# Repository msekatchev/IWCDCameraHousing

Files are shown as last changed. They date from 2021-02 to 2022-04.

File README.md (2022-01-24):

# IWCDCameraHousing

* metalHousingDesign contains SolidWorks files for the metal housing, and engineering drawings for the parts that need to be machined. 
  * Material purchase list can be found [here](https://docs.google.com/spreadsheets/d/14c0sQv2Obbbmb6hUaK7rj2h6zKZg8cWHZIx4L92i6jI/edit?usp=sharing)
  * Slides describing housing design components and how they fit together can be found [here](https://docs.google.com/presentation/d/12adMD3R-Cg0-MqwHe-JcQx2A3TCLKN2Yq-lHiGlGRaA/edit?usp=sharing)

Both the EzTops and Nautilus models are currently with the original cylinder length.
They use XDE2534.SLDPRT (original length pipe) instead of XDE2534-cut.SLDPRT (my cut pipe) because changing the pipe length breaks all of the mates between the parts. I haven't found a simple fix for this yet.

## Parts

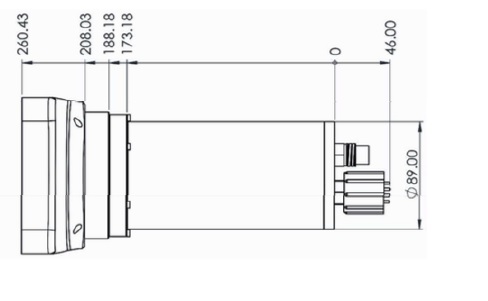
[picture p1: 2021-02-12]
solidworks parts and assembly/camera.jpg

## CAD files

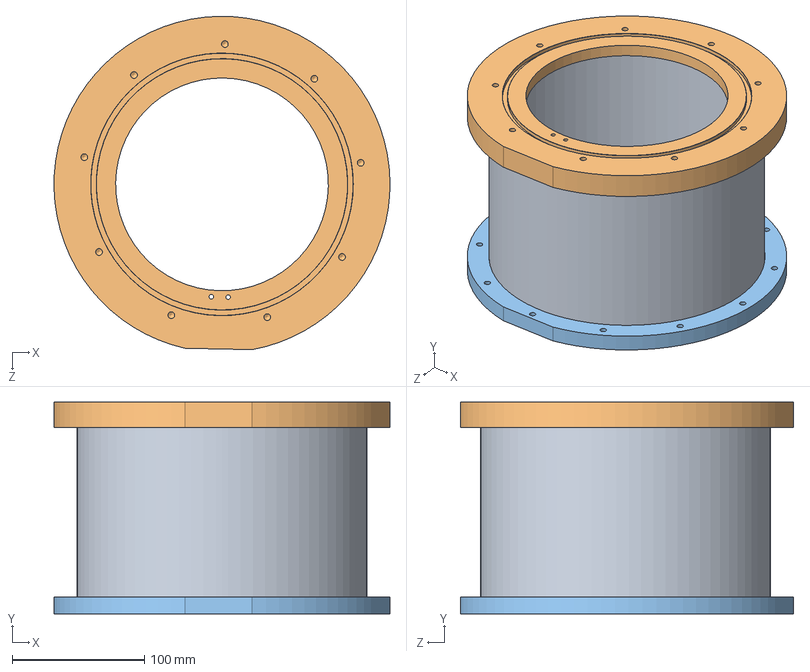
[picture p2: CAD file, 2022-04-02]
metalHousingDesign/Rayotek-Welded-Assembly.SLDASM
253.9 x 160.0 x 251.9 mm
XDE2534
XDE2535
XDE2536

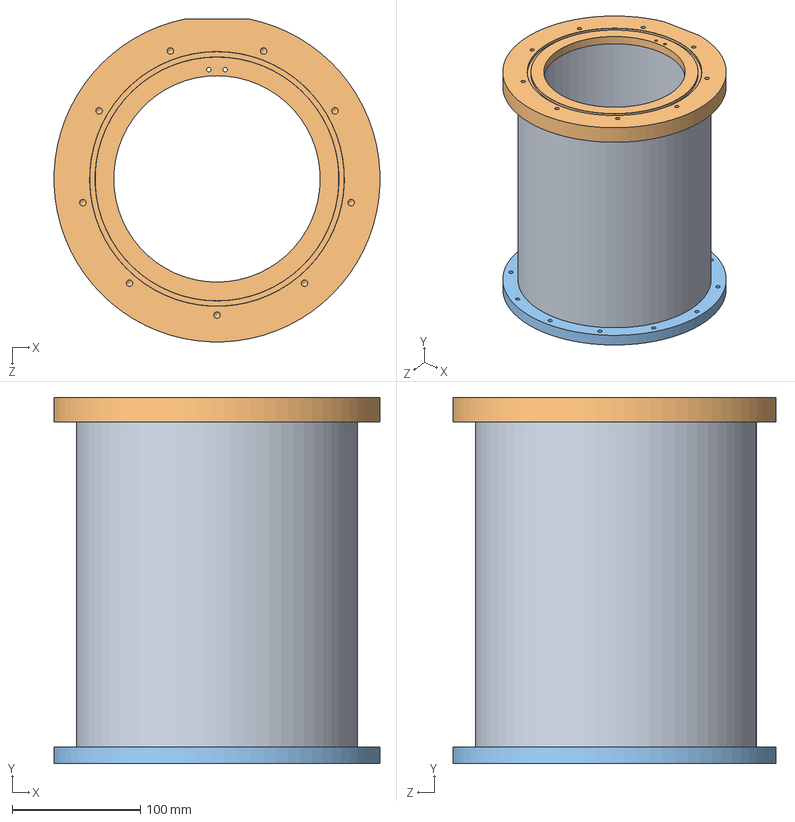
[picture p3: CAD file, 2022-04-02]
metalHousingDesign/XDE2533.SLDASM
253.8 x 285.1 x 251.3 mm
XDE2534
XDE2535
XDE2536

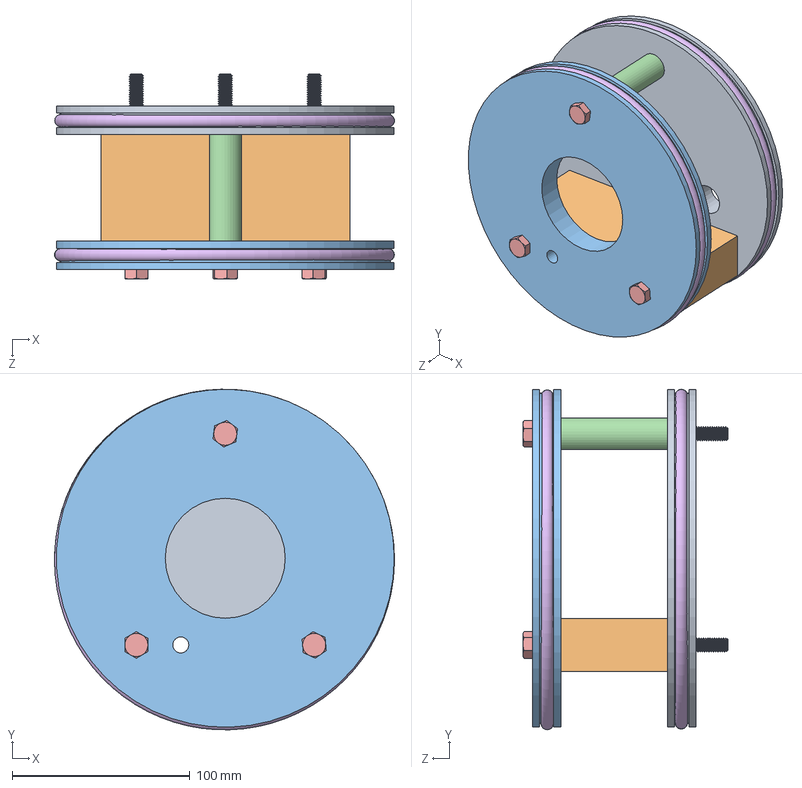
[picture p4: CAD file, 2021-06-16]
solidworks parts and assembly/piston-Assembly.SLDASM
191.2 x 191.5 x 115.3 mm
piston-BackRing
piston-CameraPlate
piston-FrontRing
piston-SpacerTube
BOLT M8x110mm x 3
piston-7inO-RING x 2

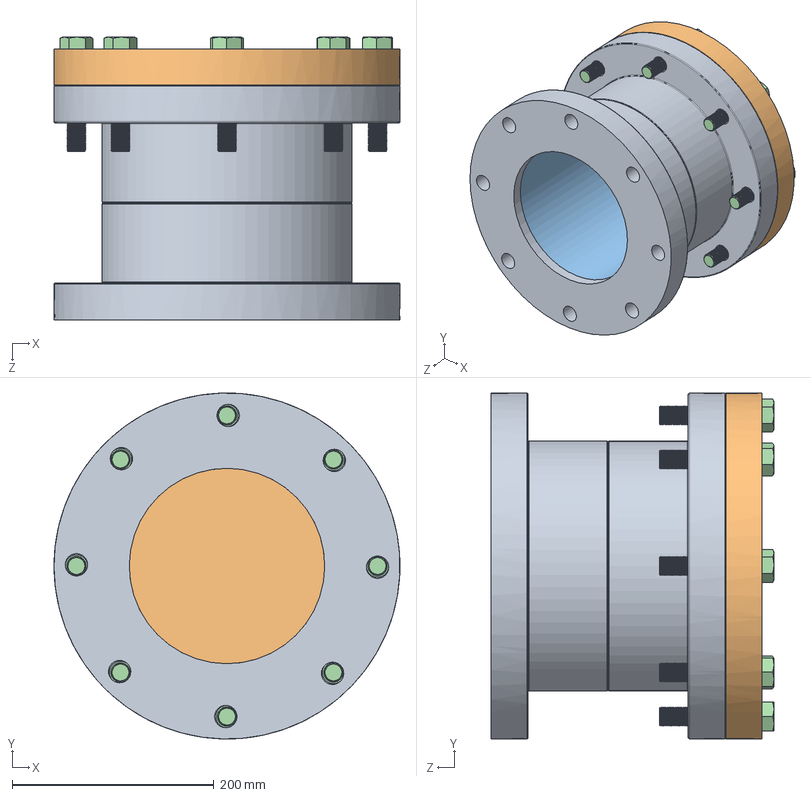
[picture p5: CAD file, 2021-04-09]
solidworks parts and assembly/externalHousing-Assembly.SLDASM
342.9 x 342.8 x 280.2 mm
8in PVC Flange x 2
8in PVC Flange Closed
8in PVC Pipe
BOLT 3-4in x 4in x 8

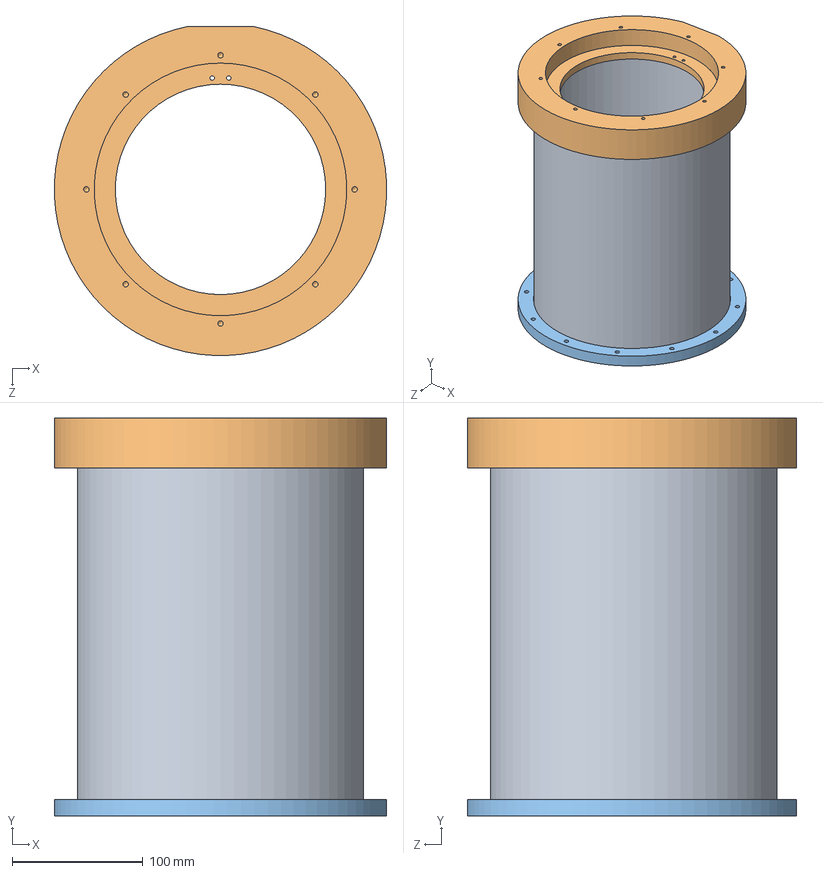
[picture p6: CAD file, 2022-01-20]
metalHousingDesign/XDE2554.SLDASM
253.8 x 304.1 x 251.3 mm
XDE2534
XDE2540
XDE2536

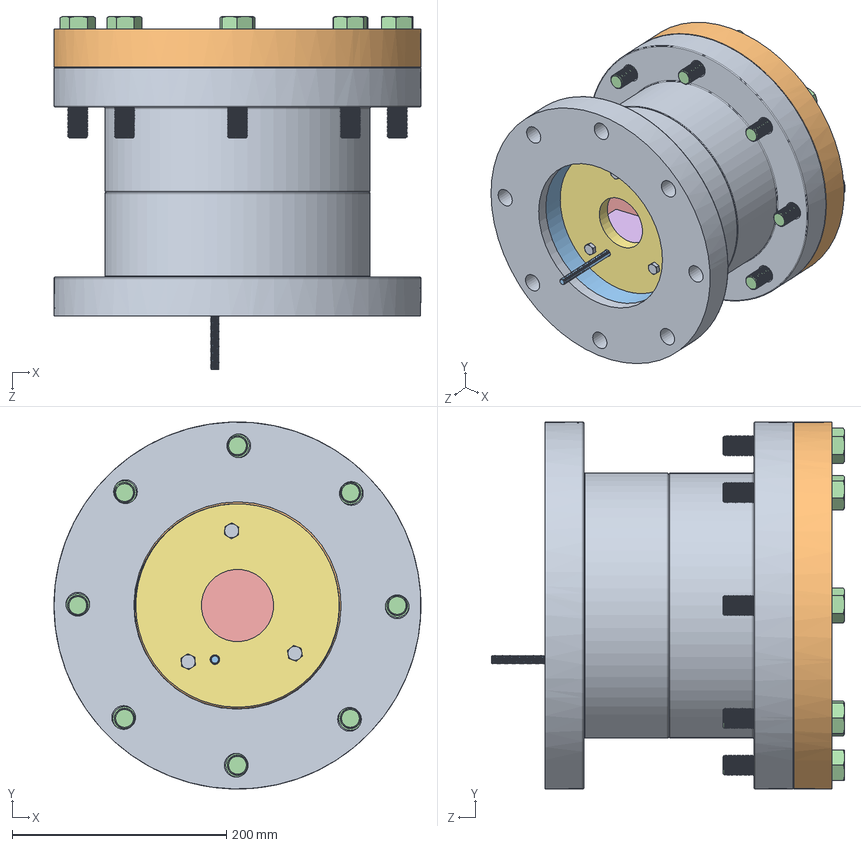
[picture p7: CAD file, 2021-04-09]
solidworks parts and assembly/Photogrametry_V5-PVC.SLDASM
342.9 x 342.8 x 330.2 mm
8in PVC Flange x 2
8in PVC Flange Closed
8in PVC Pipe
BOLT 3-4in x 4in x 8
piston-BackRing
piston-CameraPlate
piston-FrontRing
piston-SpacerTube
BOLT M8x110mm x 3
piston-7inO-RING x 2
ROD M8 150mm
SPRING

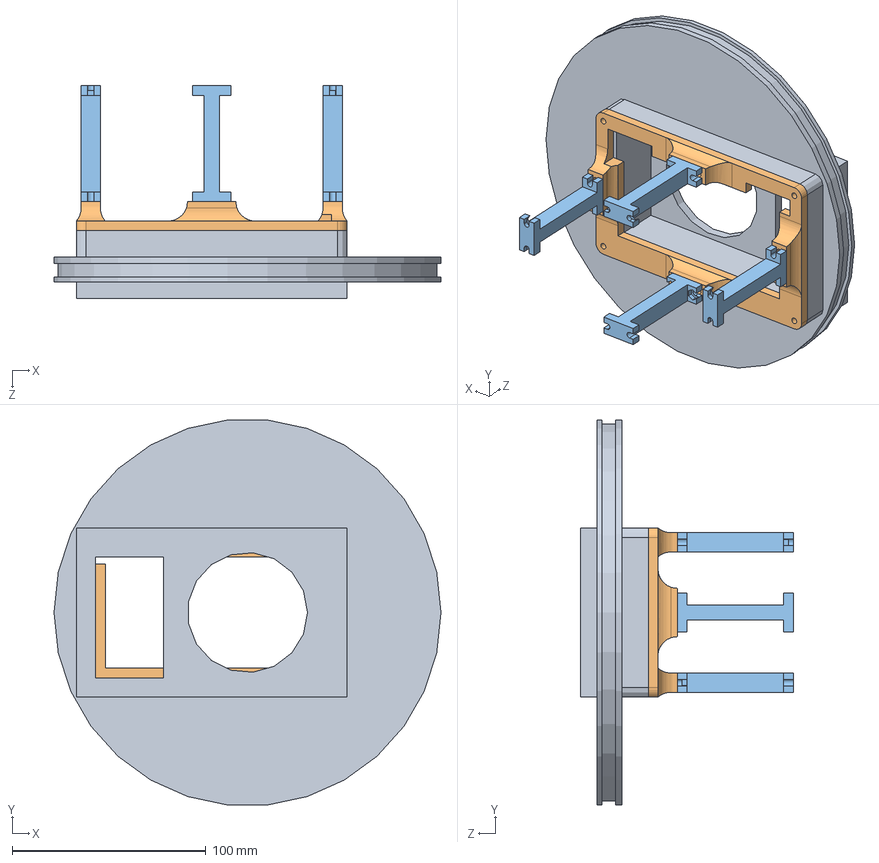
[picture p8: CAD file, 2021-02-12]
solidworks parts and assembly/Camera Mounting_V2.SLDASM
200.0 x 198.9 x 110.0 mm
Camera Case V2
Camera Case-2_V2
Pillars x 4

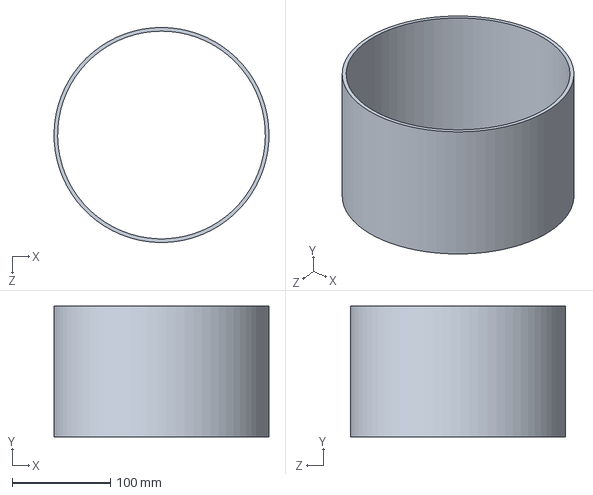
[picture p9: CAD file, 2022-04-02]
metalHousingDesign/XDE2534.SLDPRT
219.0 x 133.4 x 219.1 mm

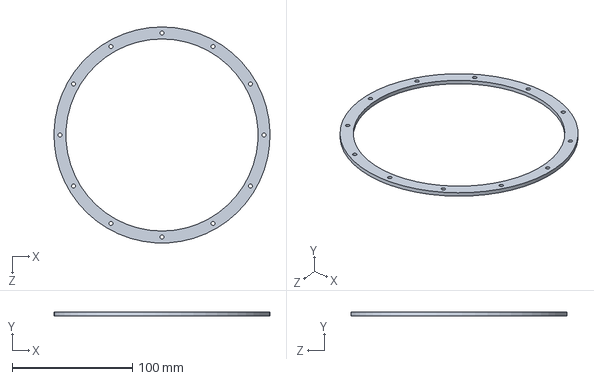
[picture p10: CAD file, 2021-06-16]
solidworks parts and assembly/PVC Parts/clamp-ring.SLDPRT
179.9 x 3.00 x 180.0 mm

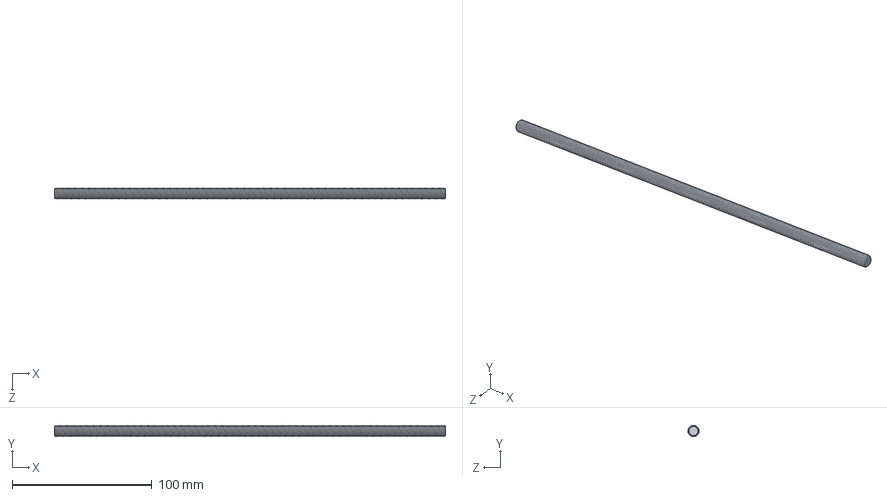
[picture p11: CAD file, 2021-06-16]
solidworks parts and assembly/ROD M8 150mm.SLDPRT
280.0 x 8.00 x 8.00 mm

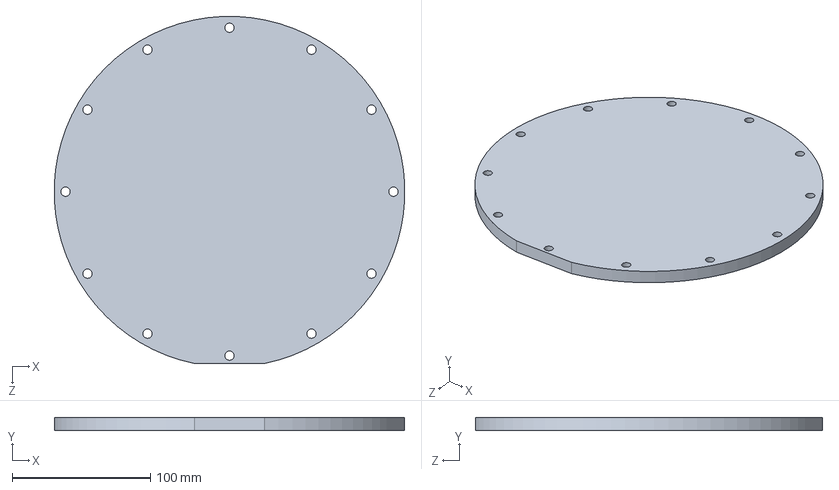
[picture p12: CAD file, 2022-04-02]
metalHousingDesign/XDE2537-blank.SLDPRT
253.8 x 9.53 x 251.3 mm

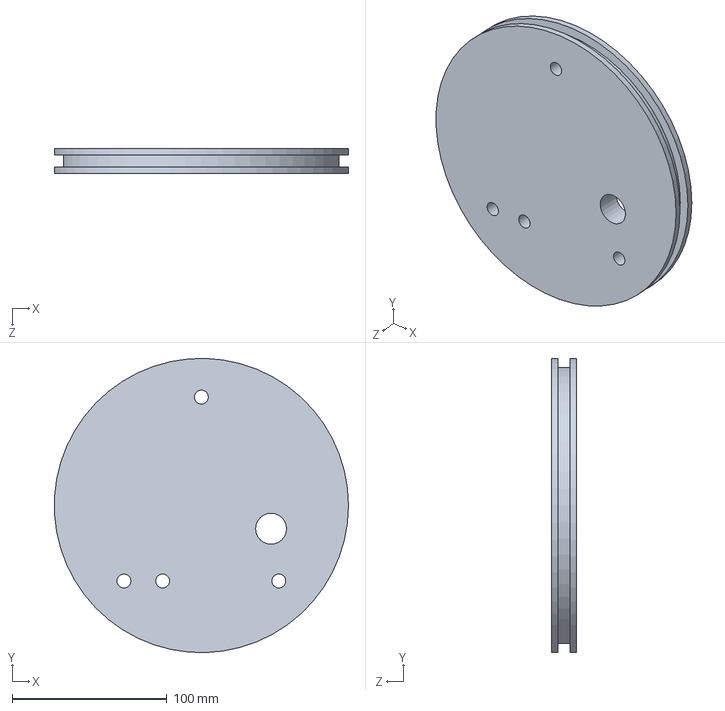
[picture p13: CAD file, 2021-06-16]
solidworks parts and assembly/piston-BackRing.SLDPRT
189.8 x 189.9 x 16.0 mm

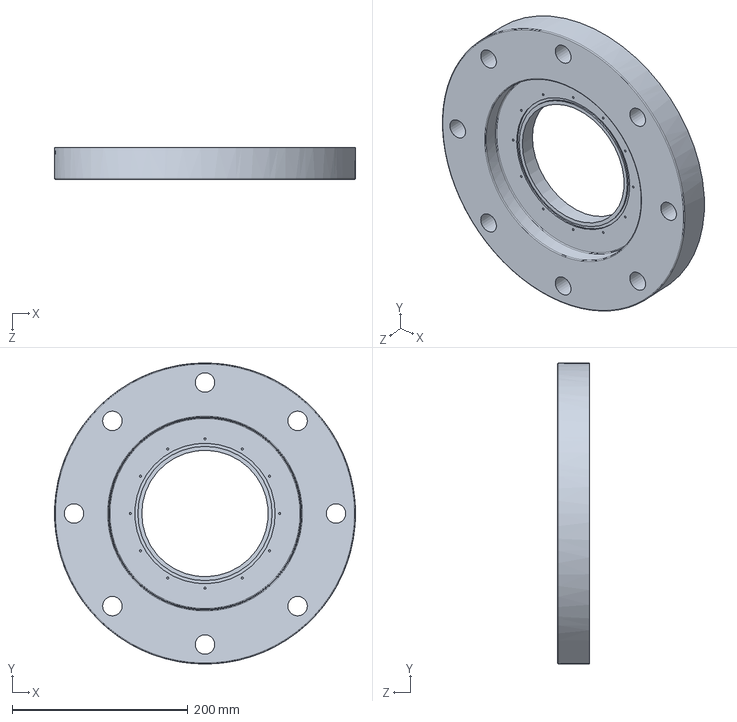
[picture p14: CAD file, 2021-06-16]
solidworks parts and assembly/PVC Parts/8in PVC Flange Closed - Dome Mount Cut.SLDPRT
342.9 x 342.8 x 36.5 mm

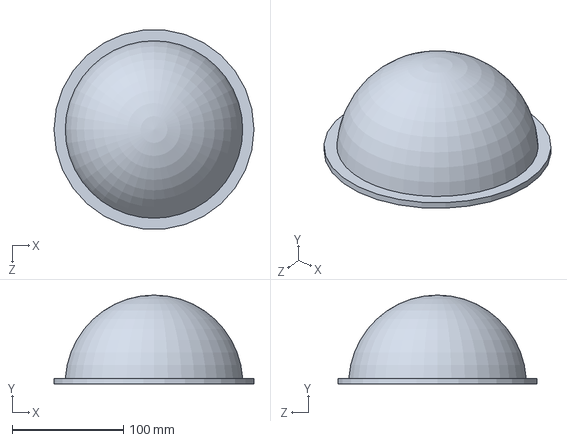
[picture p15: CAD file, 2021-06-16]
solidworks parts and assembly/Custom Dome.SLDPRT
180.0 x 80.0 x 179.0 mm

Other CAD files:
solidworks parts and assembly/PVC Parts/8in PVC Flange Closed - Dome Hole.SLDPRT
solidworks parts and assembly/piston-FrontRing.SLDPRT
solidworks parts and assembly/PVC Parts/8in PVC Cap.SLDPRT
metalHousingDesign/6 INCH Rayotek Dome.SLDPRT
metalHousingDesign/Drawings/4347K421_Thin-Wall 304 304L Stainless Steel Unthreaded Pipe.SLDDRW
metalHousingDesign/Drawings/4347K421_Thin-Wall 304 304L Stainless Steel Unthreaded Pipe.SLDPRT
metalHousingDesign/Drawings/PMTFitting.SLDDRW
metalHousingDesign/Drawings/Rayotek-Welded-Assembly.SLDDRW
metalHousingDesign/Drawings/XDE2534.SLDDRW
metalHousingDesign/Drawings/XDE2535.SLDDRW
metalHousingDesign/Drawings/XDE2536.SLDDRW
metalHousingDesign/Drawings/XDE2537-blank.SLDDRW
metalHousingDesign/Drawings/XDE2537.SLDDRW
metalHousingDesign/Drawings/XDE2555.SLDDRW
metalHousingDesign/Drawings/XDE2556.SLDDRW
metalHousingDesign/Drawings/XDE2557.SLDDRW
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

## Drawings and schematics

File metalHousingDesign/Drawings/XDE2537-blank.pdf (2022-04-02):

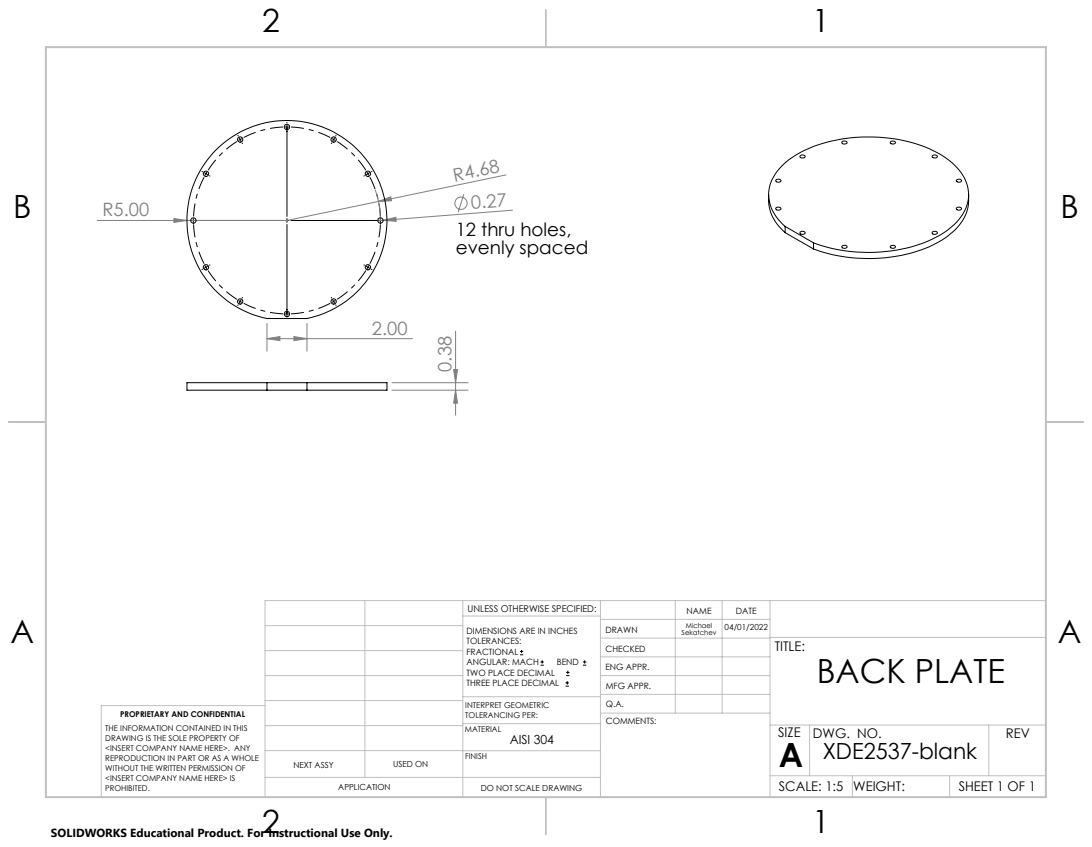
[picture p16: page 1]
12 thru holes, evenly spaced

UNLESS OTHERWISE SPECIFIED: | | NAME | DATE

DIMENSIONS ARE IN INCHES TOLERANCES: FRACTIONAL ANGULAR: MACH BEND TWO PLACE DECIMAL THREE PLACE DECIMAL | DRAWN | Michael | 04/01/2022 Sekatchev

CHECKED | | | TITLE: BACK PLATE

ENG APPR.
MFG APPR.

INTERPRET GEOMETRIC TOLERANCING PER: | Q.A.
MATERIAL AISI 304 | | SIZE A | DWG. NO. XDE2537-blank | REV

PROPRIETARY AND CONFIDENTIAL
THE INFORMATION CONTAINED IN THIS
DRAWING IS THE SOLE PROPERTY OF
<INSERT COMPANY NAME HERE>. ANY
REPRODUCTION IN PART OR AS A WHOLE
WITHOUT THE WRITTEN PERMISSION OF
<INSERT COMPANY NAME HERE> IS
PROHIBITED.

NEXT ASSY | USED ON | FINISH

APPLICATION | DO NOT SCALE DRAWING | | SCALE: 1:5 | WEIGHT: | SHEET 1 OF 1

SOLIDWORKS Educational Product. For Instructional Use Only.

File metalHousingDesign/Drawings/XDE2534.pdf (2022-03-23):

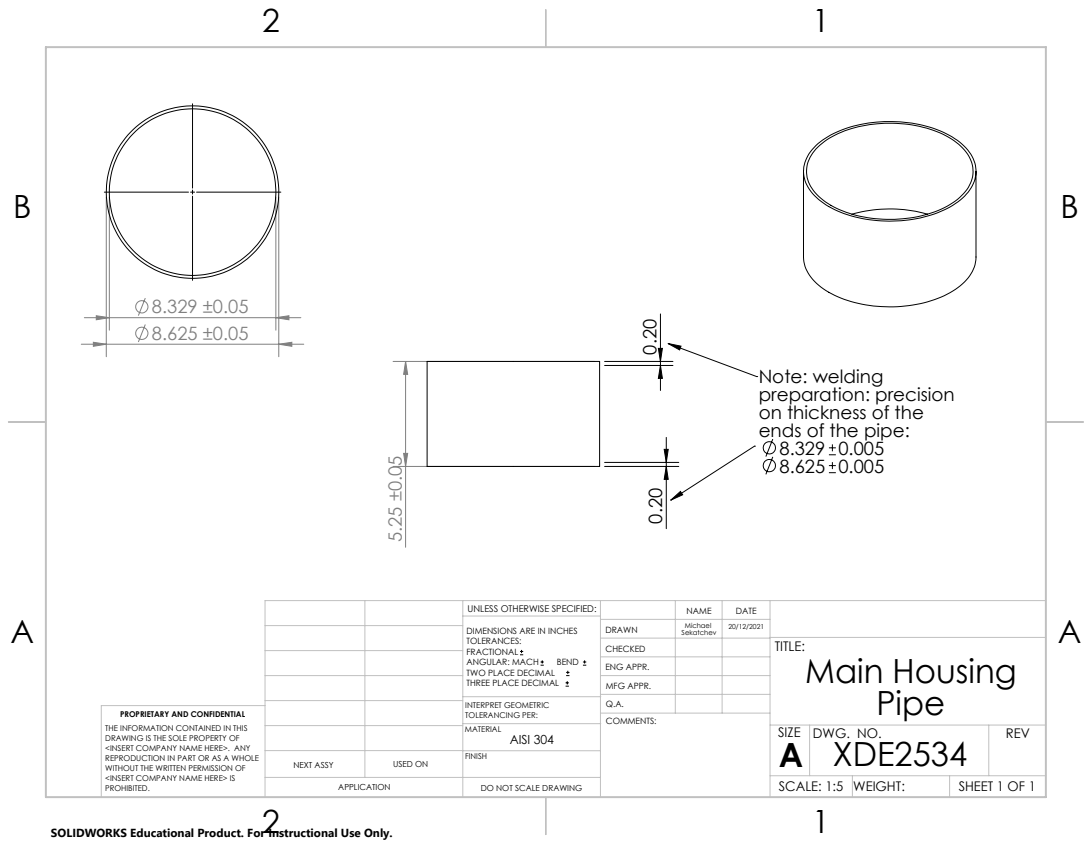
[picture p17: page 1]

Note: welding
preparation: precision
on thickness of the
ends of the pipe:

UNLESS OTHERWISE SPECIFIED: | | NAME | DATE

DIMENSIONS ARE IN INCHES TOLERANCES: FRACTIONAL ANGULAR: MACH BEND TWO PLACE DECIMAL THREE PLACE DECIMAL | DRAWN | Michael | 20/12/2021 Sekatchev

CHECKED | | | TITLE: Main Housing Pipe

ENG APPR.
MFG APPR.

INTERPRET GEOMETRIC TOLERANCING PER: | Q.A.
MATERIAL AISI 304 | | SIZE A | DWG. NO. XDE2534 | REV

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

NEXT ASSY | USED ON | FINISH

APPLICATION | DO NOT SCALE DRAWING | | SCALE: 1:5 | WEIGHT: | SHEET 1 OF 1

SOLIDWORKS Educational Product. For Instructional Use Only.

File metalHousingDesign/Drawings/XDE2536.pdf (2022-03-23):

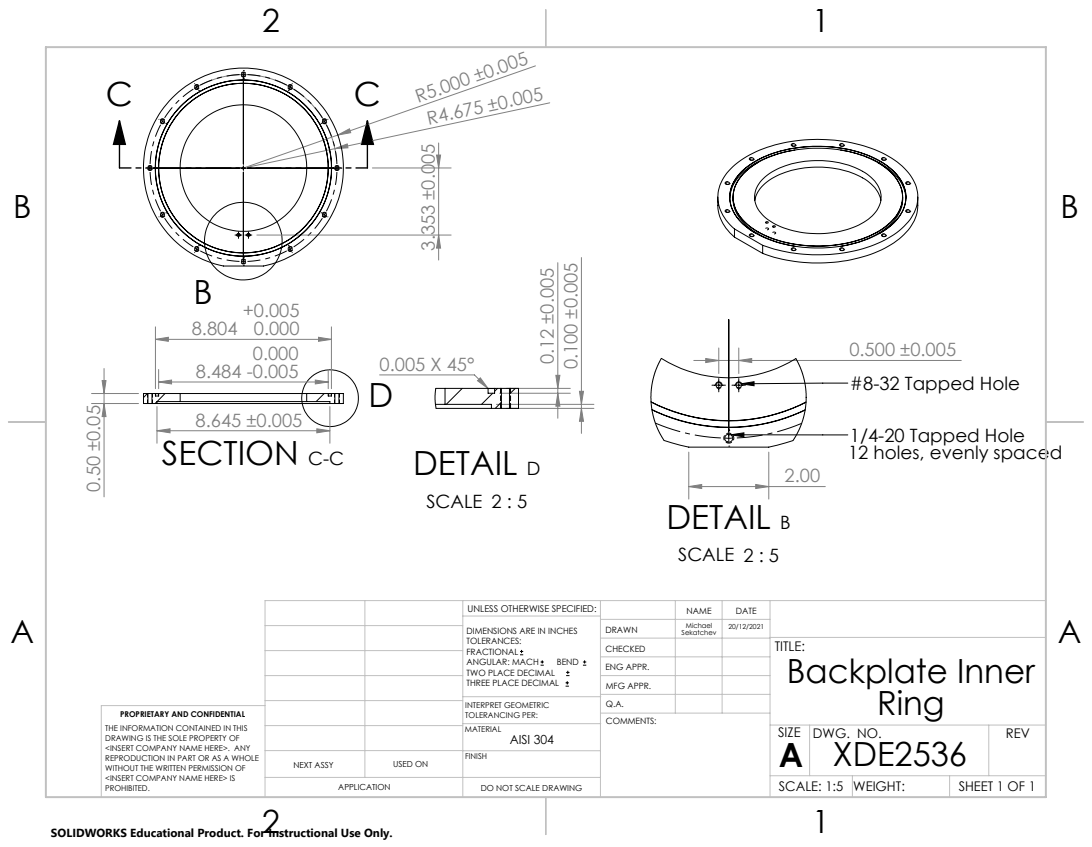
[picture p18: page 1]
SCALE 2 : 5; #8-32 Tapped Hole; SECTION C-C; DETAIL D

1/4-20 Tapped Hole
12 holes, evenly spaced
DETAIL B

UNLESS OTHERWISE SPECIFIED: | | NAME | DATE

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

CHECKED | | | TITLE: Backplate Inner Ring

ENG APPR.
MFG APPR.

INTERPRET GEOMETRIC TOLERANCING PER: | Q.A.
MATERIAL AISI 304 | | SIZE A | DWG. NO. XDE2536 | REV

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

NEXT ASSY | USED ON | FINISH

APPLICATION | DO NOT SCALE DRAWING | | SCALE: 1:5 | WEIGHT: | SHEET 1 OF 1

SOLIDWORKS Educational Product. For Instructional Use Only.

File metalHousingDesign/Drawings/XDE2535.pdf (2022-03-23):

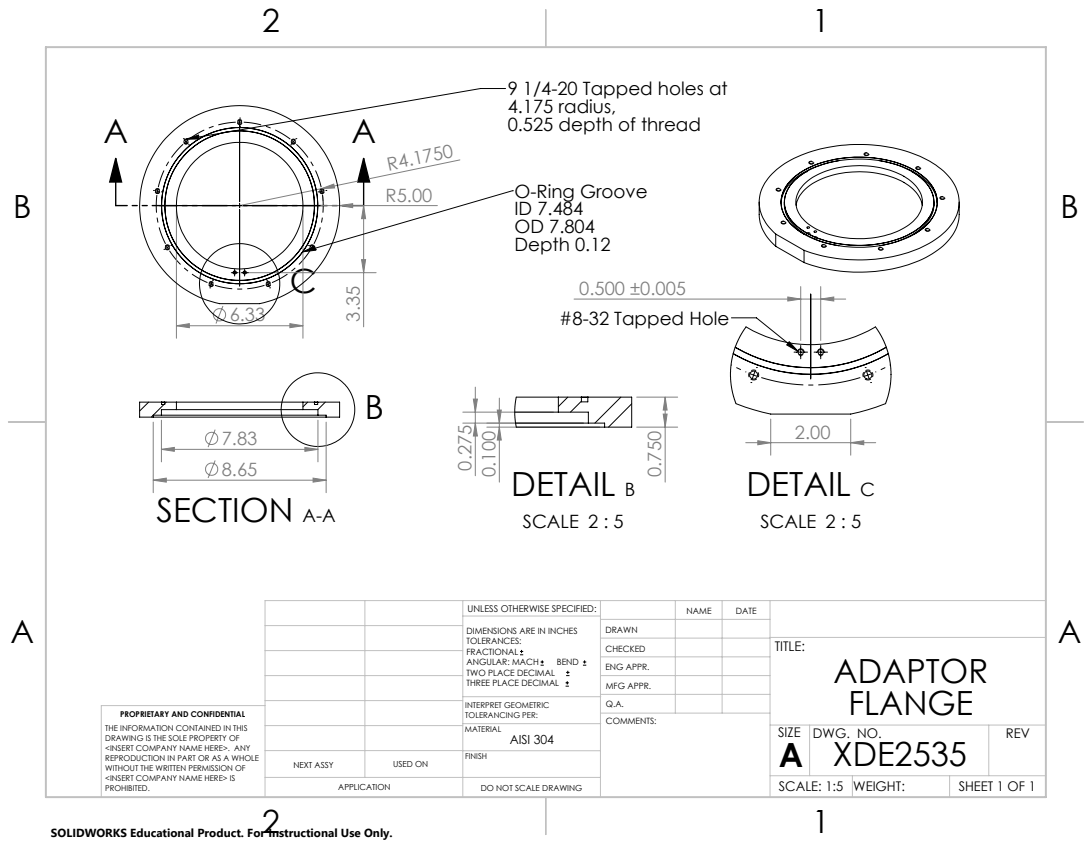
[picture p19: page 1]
O-Ring Groove ID 7.484 OD 7.804 Depth 0.12; SECTION A-A; DETAIL B; SCALE 2 : 5; DETAIL C; #8-32 Tapped Hole

9 1/4-20 Tapped holes at
4.175 radius,
0.525 depth of thread

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

CHECKED | | | TITLE: ADAPTOR FLANGE

ENG APPR.
MFG APPR.

INTERPRET GEOMETRIC TOLERANCING PER: | Q.A.
MATERIAL AISI 304 | | SIZE A | DWG. NO. XDE2535 | REV

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

NEXT ASSY | USED ON | FINISH

APPLICATION | DO NOT SCALE DRAWING | | SCALE: 1:5 | WEIGHT: | SHEET 1 OF 1

SOLIDWORKS Educational Product. For Instructional Use Only.

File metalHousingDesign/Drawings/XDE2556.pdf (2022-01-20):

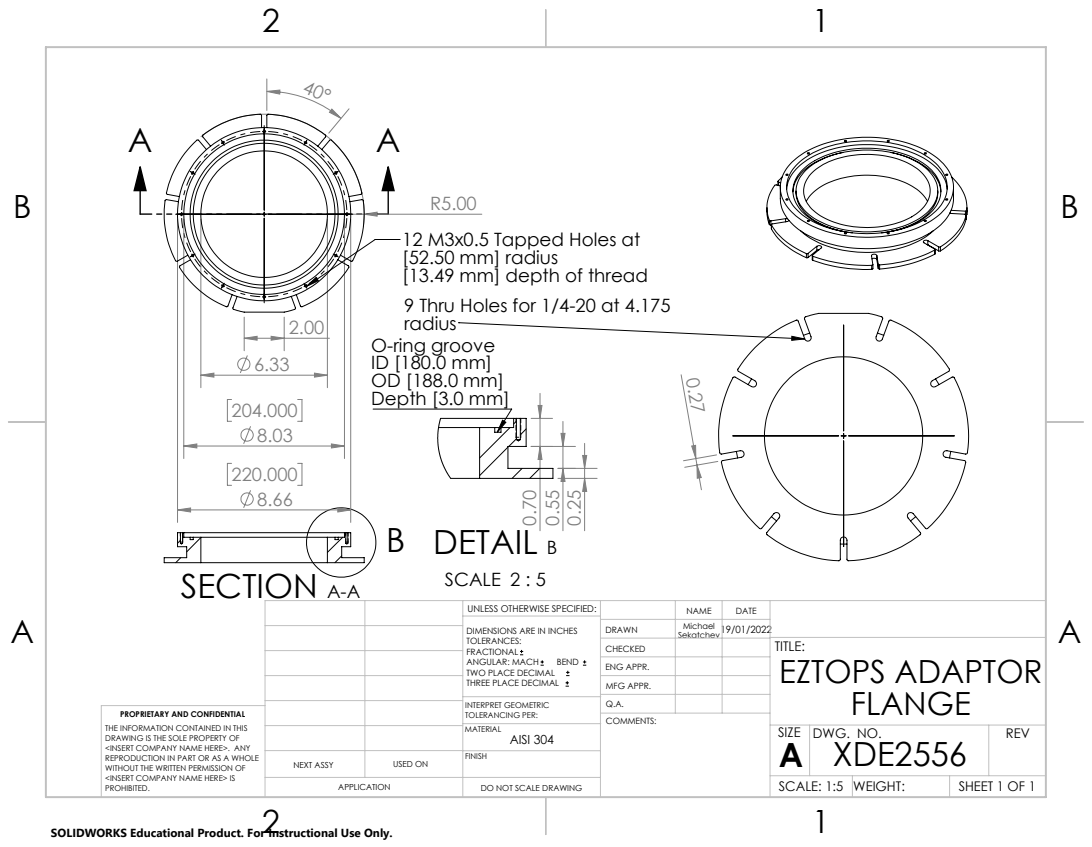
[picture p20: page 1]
SECTION A-A; DETAIL B; SCALE 2 : 5; Depth [3.0 mm]

12 M3x0.5 Tapped Holes at
[52.50 mm] radius
[13.49 mm] depth of thread
9 Thru Holes for 1/4-20 at 4.175
radius
O-ring groove

UNLESS OTHERWISE SPECIFIED: | | NAME | DATE
DIMENSIONS ARE IN INCHES TOLERANCES: FRACTIONAL ANGULAR: MACH BEND TWO PLACE DECIMAL THREE PLACE DECIMAL | DRAWN | Michael 19/01/2022 Sekatchev

CHECKED | | | TITLE: EZTOPS ADAPTOR FLANGE

ENG APPR.
MFG APPR.

INTERPRET GEOMETRIC TOLERANCING PER: | Q.A.
MATERIAL AISI 304 | | SIZE A | DWG. NO. XDE2556 | REV

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

NEXT ASSY | USED ON | FINISH

APPLICATION | DO NOT SCALE DRAWING | | SCALE: 1:5 | WEIGHT: | SHEET 1 OF 1

SOLIDWORKS Educational Product. For Instructional Use Only.

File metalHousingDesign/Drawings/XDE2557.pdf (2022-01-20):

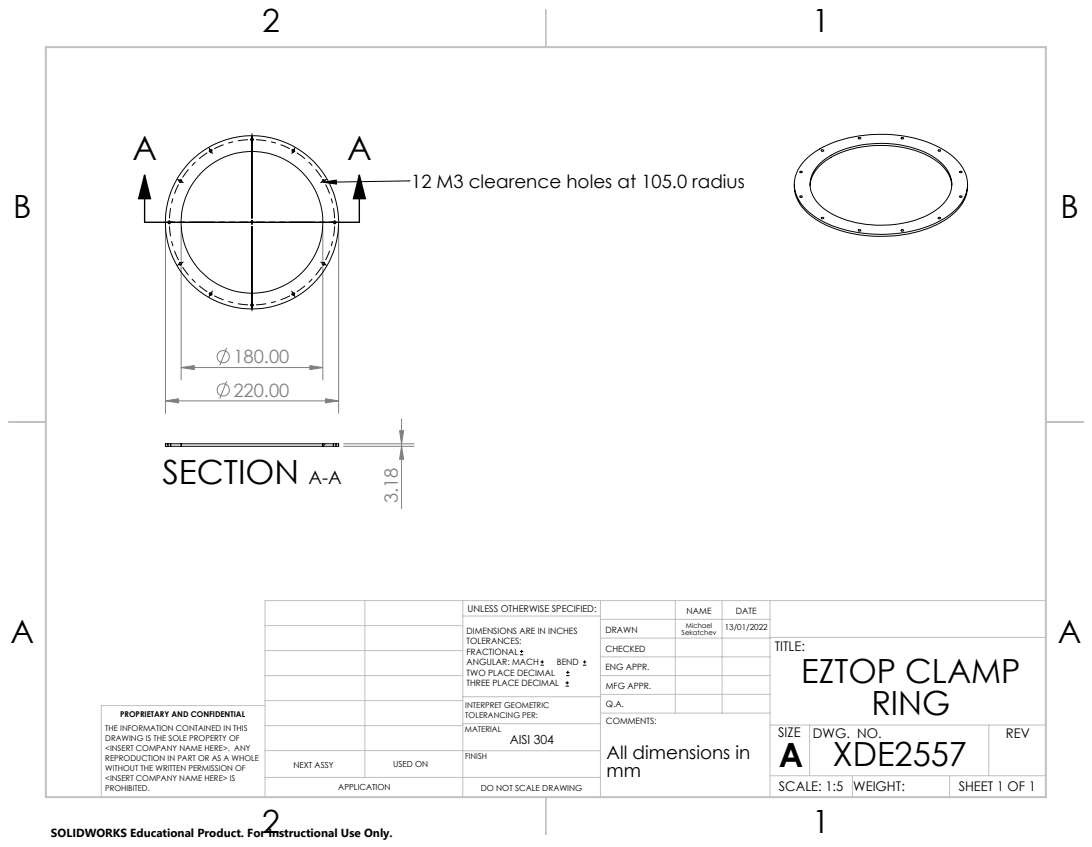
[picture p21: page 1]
SECTION A-A

12 M3 clearence holes at 105.0 radius

UNLESS OTHERWISE SPECIFIED: | | NAME | DATE

DIMENSIONS ARE IN INCHES TOLERANCES: FRACTIONAL ANGULAR: MACH BEND TWO PLACE DECIMAL THREE PLACE DECIMAL | DRAWN | Michael | 13/01/2022 Sekatchev

CHECKED | | | TITLE: EZTOP CLAMP RING

ENG APPR.
MFG APPR.

INTERPRET GEOMETRIC TOLERANCING PER: | Q.A.
MATERIAL AISI 304 | | SIZE A | DWG. NO. XDE2557 | REV

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

COMMENTS:
All dimensions in

NEXT ASSY | USED ON | FINISH

APPLICATION | DO NOT SCALE DRAWING | | SCALE: 1:5 | WEIGHT: | SHEET 1 OF 1

SOLIDWORKS Educational Product. For Instructional Use Only.

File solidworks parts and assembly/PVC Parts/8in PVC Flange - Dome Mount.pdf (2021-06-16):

B B

2

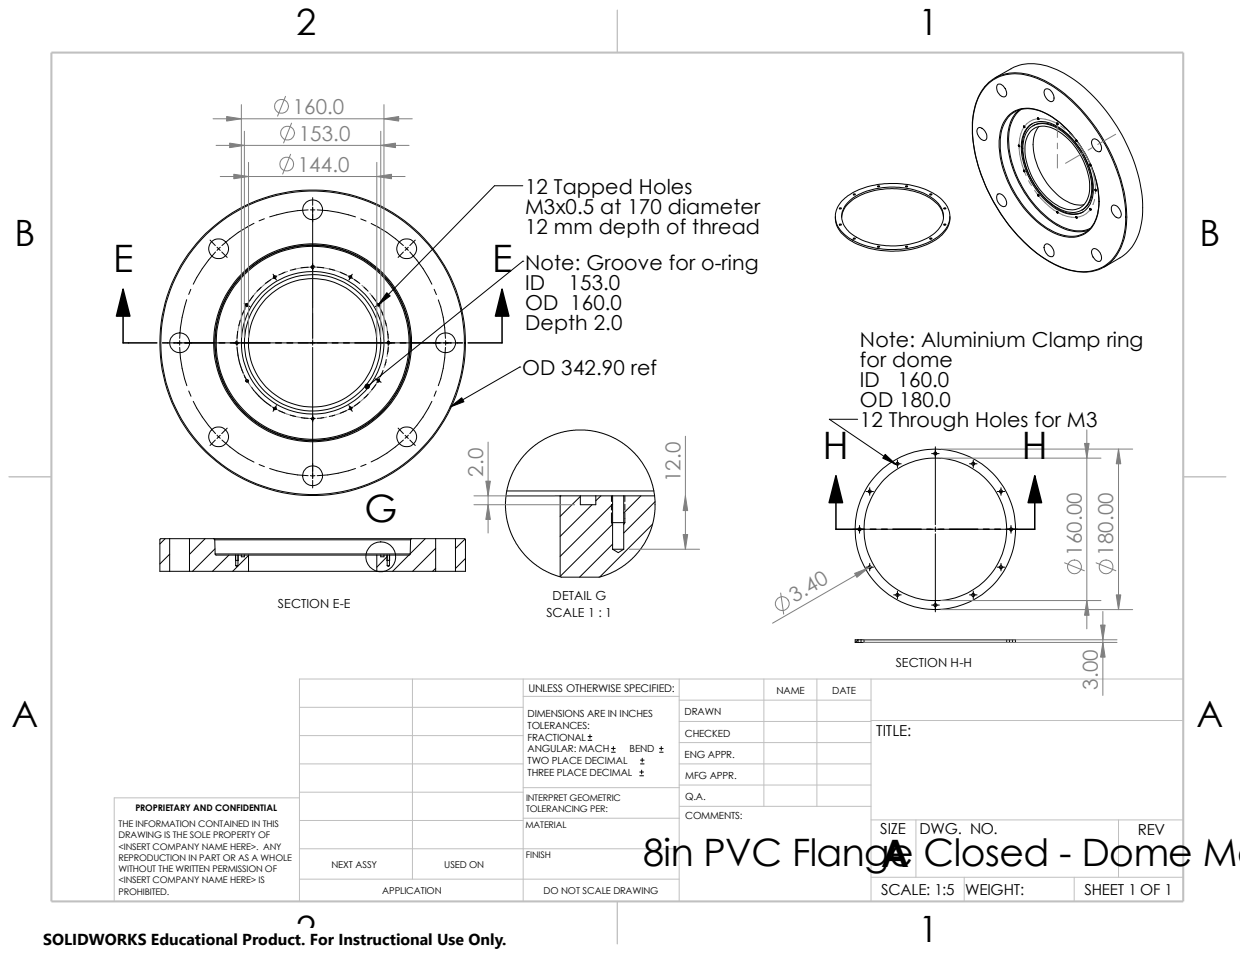
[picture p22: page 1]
12 Through Holes for M3160.00; SECTION E-E; DETAIL G; SCALE 1 : 1 ².0; SECTION H-H

12 Tapped Holes
M3x0.5 at 170 diameter
12 mm depth of thread
Note: Groove for o-ring
Depth 2.0
OD 342.90 ref

Note: Aluminium Clamp ring
for dome

UNLESS OTHERWISE SPECIFIED: | | NAME | DATE

DIMENSIONS ARE IN INCHES TOLERANCES: FRACTIONAL ANGULAR: MACH BEND TWO PLACE DECIMAL THREE PLACE DECIMAL | DRAWN

CHECKED | | | TITLE:

ENG APPR.
MFG APPR.

INTERPRET GEOMETRIC TOLERANCING PER: | Q.A.
MATERIAL | | SIZE A | DWG. NO. | REV

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

COMMENTS:
8in PVC Flange Closed - Dome Mount Cut

NEXT ASSY | USED ON | FINISH

APPLICATION | DO NOT SCALE DRAWING | | SCALE: 1:5 | WEIGHT: | SHEET 1 OF 1

SOLIDWORKS Educational Product. For Instructional Use Only.

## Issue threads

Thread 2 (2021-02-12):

Separate ring structure (piston) into different parts

msekatchev, 2021-02-12:
Rings structure holding camera in place is current 1 solidworks part file.
Need to split it into 2 rings and 1 tripod mount base.

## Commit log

2021-02-12 Upload of Michael's new concept
    New concept described here:
    https://docs.google.com/presentation/d/1cinUeYIUWecYwROuaX7O0PpBMZb3fojsMDkA2N6fbMg/edit?usp=sharing
    [3060T850_SQUARE U-BOLT.SLDPRT, BOLT M6x30.SLDPRT, BOLT M6x40.SLDPRT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]
2021-06-16 Add files via upload
    Made a proper model of the dome port & dome assembly, and mated everything together correctly. Cut distance controlling rod to size.
    [Custom Dome.SLDPRT, ROD M8 150mm.SLDPRT, piston-Assembly.SLDASM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]
2022-01-20 Added metal housing design
    [4347K421_Thin-Wall 304 304L Stainless Steel Unthreaded Pipe.SLDDRW, 4347K421_Thin-Wall 304 304L Stainless Steel Unthreaded Pipe.SLDPRT, PMTFitting.SLDDRW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]
2022-02-07 Added 1mm red ring at 17.5 mm for nodal point
2022-02-17 Add files via upload
    Updated length of pipe to 5.25"
    [XDE2534.SLDDRW]
2022-03-23 Fixed missing dimension: #8-32 holes, missing y-dimension from center
2022-04-02 Added blank back flange
    [XDE2537-blank.SLDDRW]
